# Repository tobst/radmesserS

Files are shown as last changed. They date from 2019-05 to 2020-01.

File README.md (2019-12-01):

# ESP32 BLE Distance Measurements

Distance Measurement HC-SR04 sensors connected to ESP32 pretending to be heart rate sensor for logging with fitness apps.

## Description

Inspired by the Berlin project Radmesser, this version connects to tracking apps by pretending to be a heart rate sensor. This enables you to write the distance to a gpx file and use it later in video editing software like [Dashware](http://www.dashware.net/) or [Garmin Virb Edit](https://buy.garmin.com/de-DE/DE/p/573412) to show the distance in your video.

More information can be found in the project wiki, [see here](https://github.com/tobst/radmesserS/wiki).

## Getting Started

### Hardware

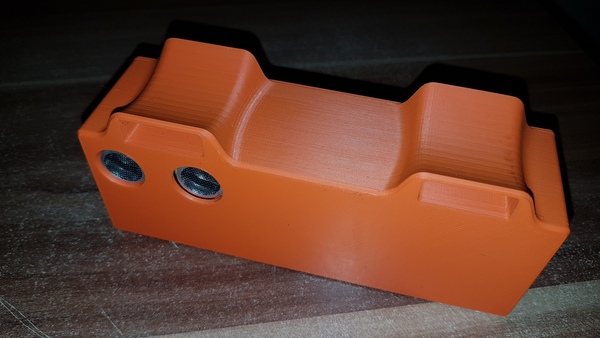
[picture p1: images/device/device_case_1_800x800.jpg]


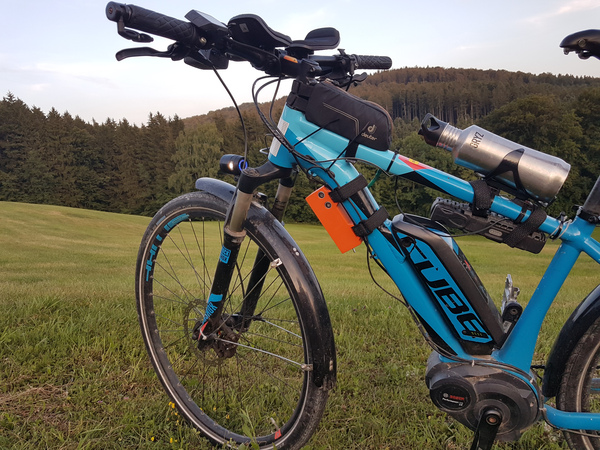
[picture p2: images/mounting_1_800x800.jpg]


The prototype by [Zweirat](https://zweirat-stuttgart.de/projekte/radmesser/) used the following:
* [ESP32](https://www.az-delivery.de/products/esp32-developmentboard)
* [LiFePo-Battery](https://www.akkuteile.de/lifepo-akkus/18650/a123-apr18650m-a1-1100mah-3-2v-3-3v-lifepo4-akku/a-1006861/)
* [Battery-Protection-Board](https://www.ebay.de/itm/202033076322)
* [LiFePo charging module](https://www.ebay.de/itm/MicroUSB-TP5000-3-6v-1A-Charger-Module-3-2v-LiFePO4-Lithium-Battery-Charging-/122164745507)
* [HC-SR04P](https://www.ebay.de/itm/183610614563)

With LiFePo Batteries you can power the device directly and avoid step-up/step-down losses that you have when using a powerbank. On the other hand you need the HC-SR04P instead of the HC-SR04 sensor if you don't have 5V power supply.

### Dependencies

* ESP32 device driver
* Neil Kolbans ESP32 BLE Library
* Arduino IDE
* [TM1637 Library](https://github.com/avishorp/TM1637) - installed through Arduino library manager
* [SSD1306 Library](https://github.com/adafruit/Adafruit_SSD1306) - installed through Arduino library manager
* [TinyGPSPlus Library](https://github.com/mikalhart/TinyGPSPlus)

### Installing

* clone or download repository
* open in Arduino IDE
* compile and upload to ESP32
* Connect sensor

### Executing program
* power up device
* Use [BLE Scanner](https://play.google.com/store/apps/details?id=com.macdom.ble.blescanner) or your favorite BLE app to send ond permanently save offset (for example the distance from sensor to handlebar)
* Start your favourite tracking app
Good results were made with [RunnerUp](https://play.google.com/store/apps/details?id=org.runnerup&hl=de), Strava had some issues on Android, look here for [alternatives](https://play.google.com/store/apps/details?id=org.runnerup&hl=de), no experience with iOS so far. 
* Connect heart rate sensor

### ToDo
* Write nice tutorial how to process video data and create synchronized overlays
* Develop an own app to record videos in loop mode and only save short clips when distance is low. At the end of the ride, ask user to confirm that a car was overtaking. Possibility to create overlays for video and report anonymous metadata of overtaking incidents (good and bad ones) to open data platform.

## Acknowledgments

Inspiration, code snippets, etc.
* [Neil Kolbans ESP32 BLE Library](https://github.com/nkolban/ESP32_BLE_Arduino)
* [Wiring up the Sensor](https://www.smarthomeng.de/entfernungsmessung-auf-basis-eines-esp32-und-smarthomeng)

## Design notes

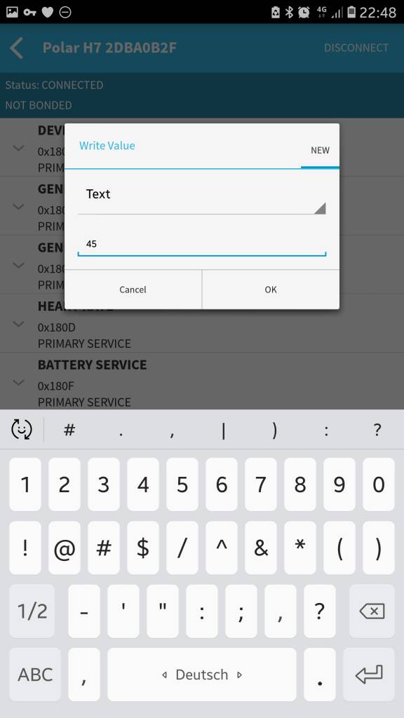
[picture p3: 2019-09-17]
images/screenshots/blescanner/ble_scanner_5.jpg

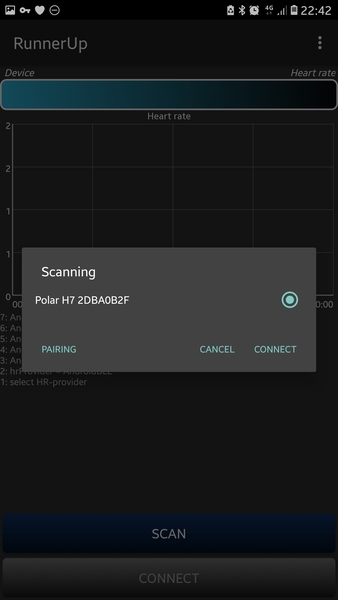
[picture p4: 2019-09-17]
images/screenshots/runnerup/runnerup_7_800x800.jpg

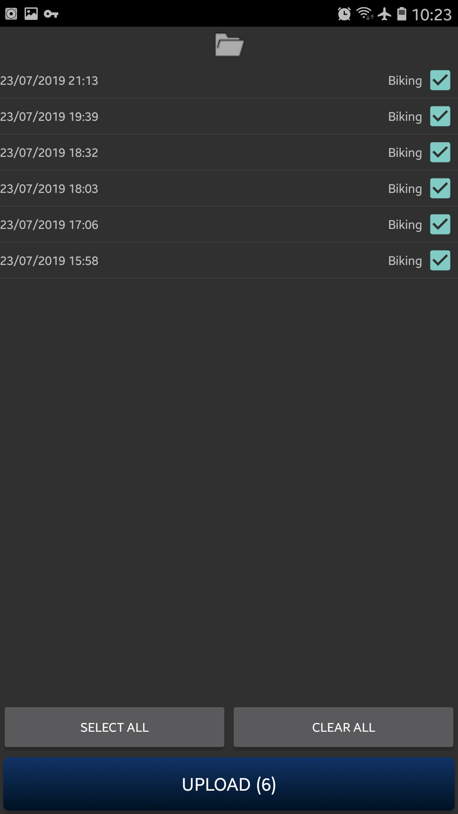
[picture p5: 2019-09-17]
images/screenshots/runnerup/export/runnerup_export_to_directory_4.jpg

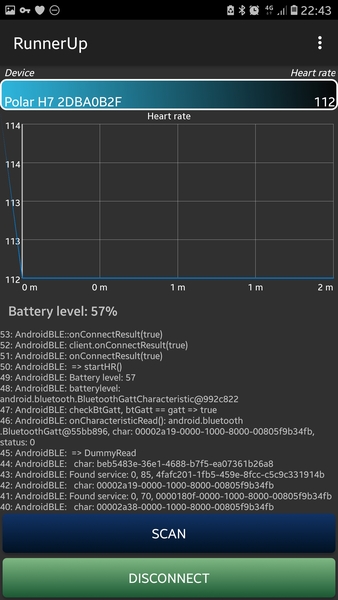
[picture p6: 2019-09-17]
images/screenshots/runnerup/runnerup_8_800x800.jpg

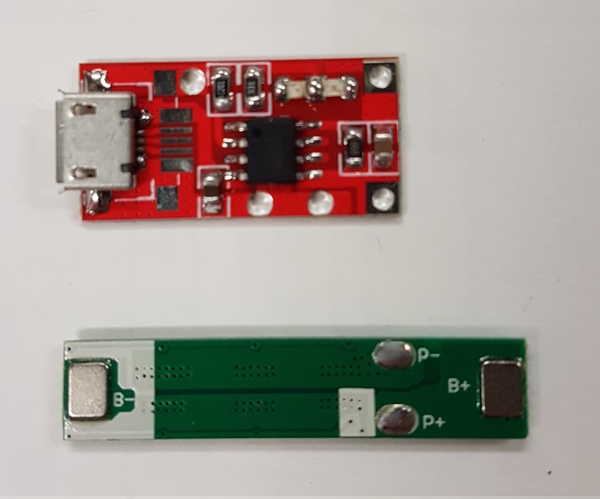
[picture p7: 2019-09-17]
images/device/TP5000-Charger-and-LiFePo-Protection-Board_800x800.jpg

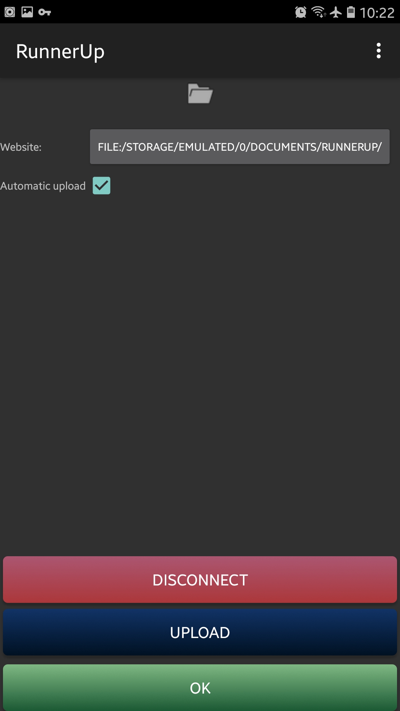
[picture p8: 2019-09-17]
images/screenshots/runnerup/export/runnerup_export_to_directory_3.jpg

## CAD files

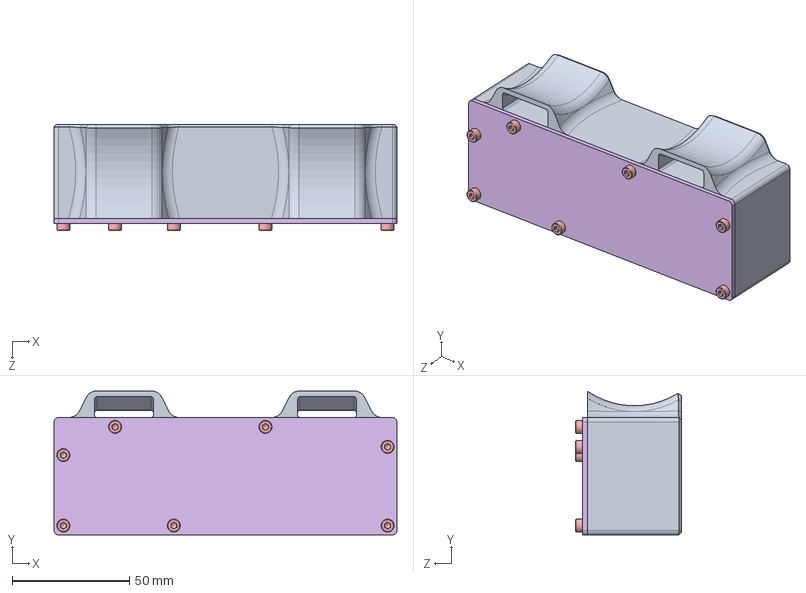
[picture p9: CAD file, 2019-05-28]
Case/TO-999.SLDASM
146.0 x 61.3 x 45.0 mm
TO-001
Battery
To-002
socket head cap screw 4762_din x 8
TP5000_placeholder
TO-004
socket head cap screw_am x 2

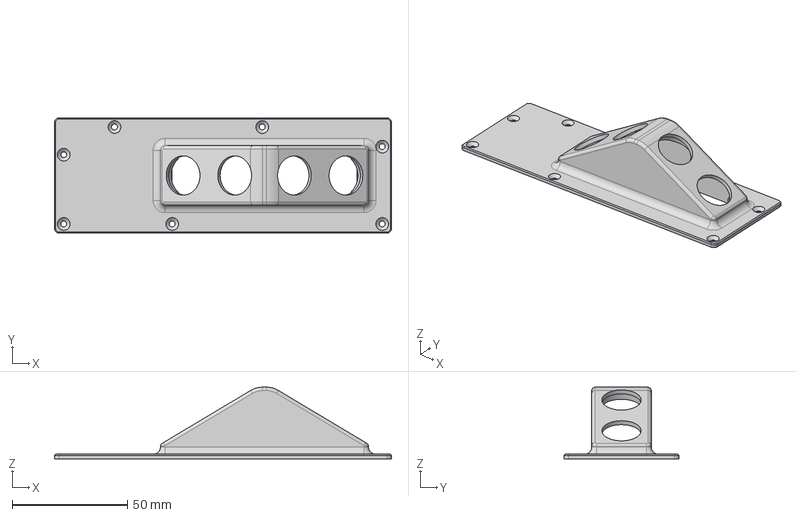
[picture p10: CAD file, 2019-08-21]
Case/TO-003_v6.step
146.0 x 50.0 x 31.1 mm

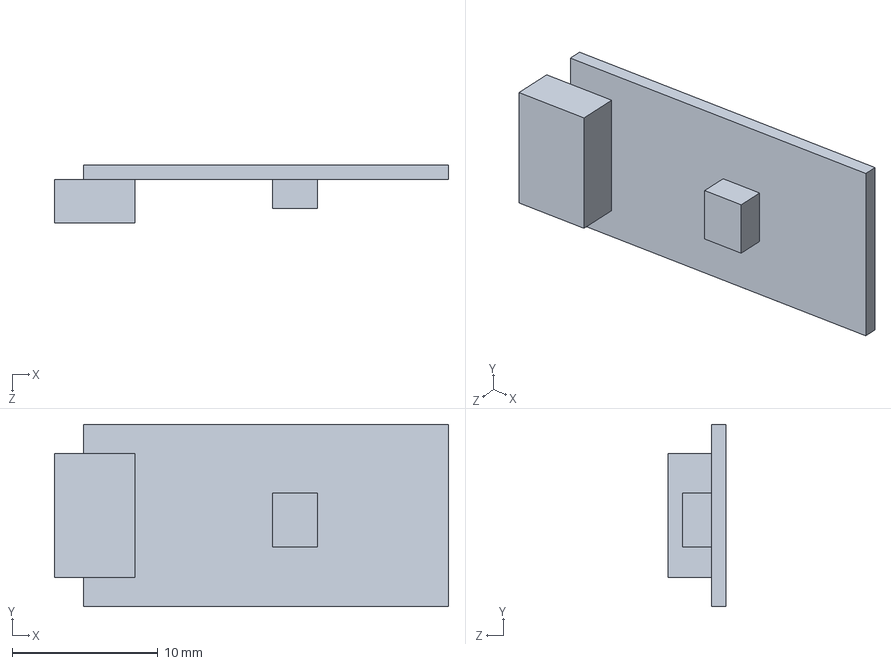
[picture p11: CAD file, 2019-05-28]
Case/TP5000_placeholder.SLDPRT
27.0 x 12.5 x 4.00 mm

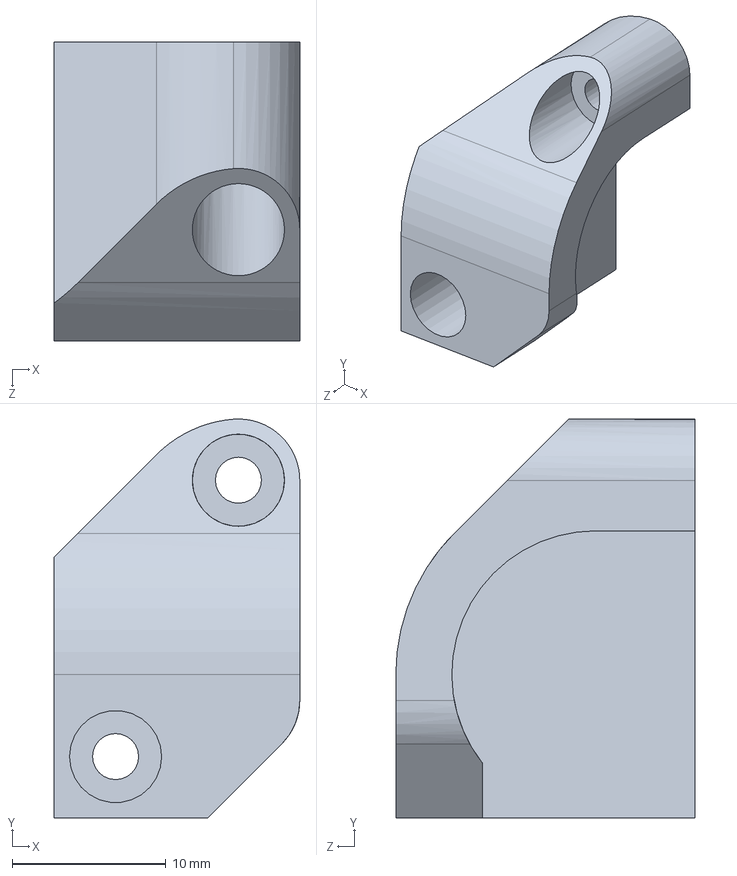
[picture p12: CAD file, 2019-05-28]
Case/To-002.SLDPRT
16.0 x 26.0 x 19.5 mm

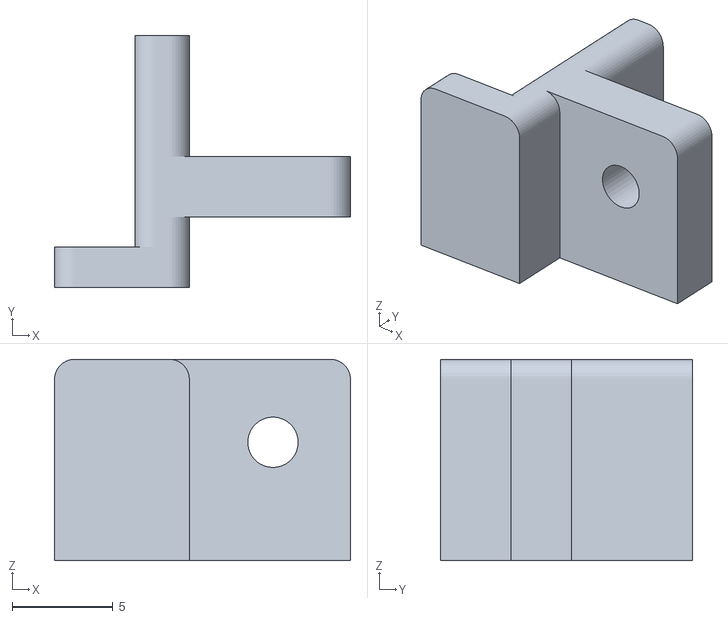
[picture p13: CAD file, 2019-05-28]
Case/TO-004_v5.STL
14.7 x 12.5 x 10.0

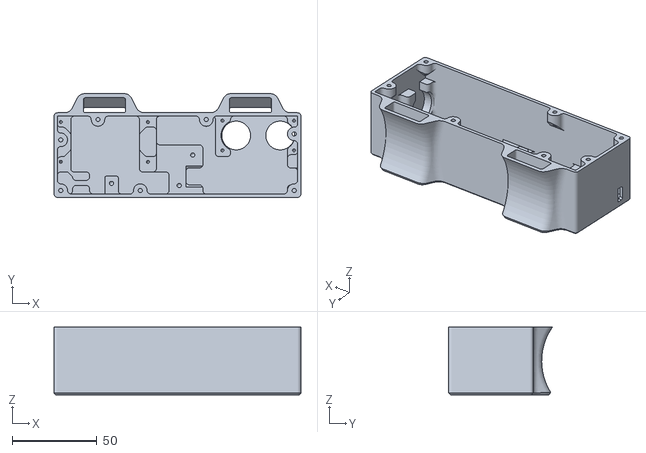
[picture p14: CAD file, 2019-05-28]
Case/TO-001_v5.STL
146.0 x 61.3 x 40.0

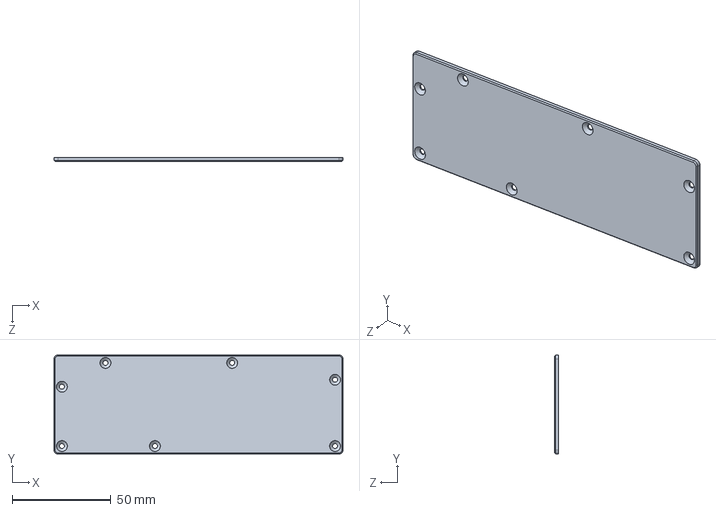
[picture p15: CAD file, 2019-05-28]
Case/TO-003.SLDPRT
146.0 x 50.0 x 2.00 mm

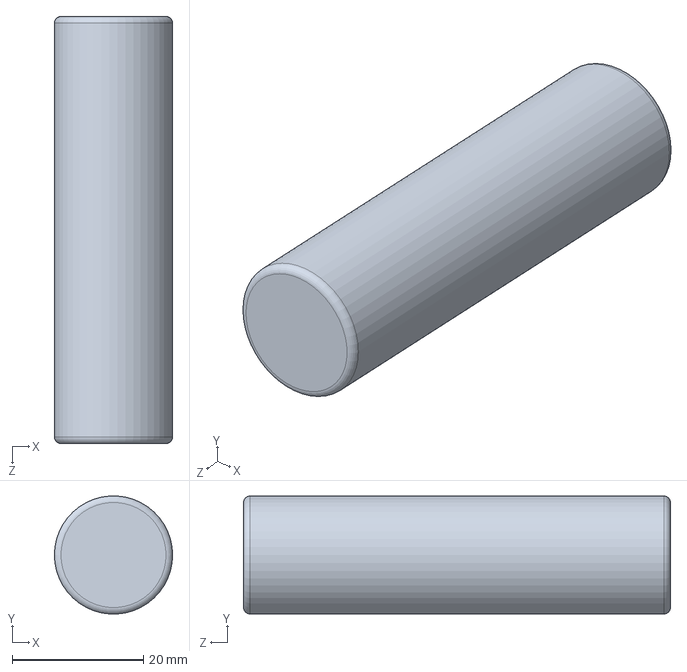
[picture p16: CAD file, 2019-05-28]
Case/Battery.SLDPRT
18.0 x 18.0 x 65.0 mm

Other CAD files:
Case/TO-001.SLDPRT
Case/TO-004.SLDPRT
Case/TO-002_v5.STL
Case/TO-003_v5.STL
Case/TO-003_v6.stl

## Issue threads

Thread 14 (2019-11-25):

use ANT+ Radar (RDR) instead of heart-rate

mfa, 2019-11-25:
https://www.thisisant.com/news/ant-wireless-releases-first-interoperable-device-profile-for-bike-radar-sen

tobst, 2019-11-27:
Good Idea. Since not all devices (e.g. IPhone) support ANT+, this should be an additional choice.

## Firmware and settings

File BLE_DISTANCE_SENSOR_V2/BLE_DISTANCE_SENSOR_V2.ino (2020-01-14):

/*
    BLE Device pretending to be a Heart Rate Measurement Device but sending distance instead

    Based on Neil Kolban example for IDF: https://github.com/nkolban/esp32-snippets/blob/master/cpp_utils/tests/BLETests/SampleNotify.cpp
    Ported to Arduino ESP32 by Evandro Copercini
    Distance Measurement by Marc Rene Friess: https://www.smarthomeng.de/entfernungsmessung-auf-basis-eines-esp32-und-smarthomeng

    Used BLE Scanner https://play.google.com/store/apps/details?id=com.macdom.ble.blescanner&hl=de to find out what original Heart Rate Sensor is doing and copied services and characteristics UUIDs

*/
#include <BLEDevice.h>
#include <BLEServer.h>
#include <BLEDescriptor.h>
#include <BLEUtils.h>
#include <BLE2902.h>
#include <Wire.h>
#include <EEPROM.h>
#define CIRCULAR_BUFFER_INT_SAFE
#include <CircularBuffer.h>
#include "displays.h"
#include "FS.h"
#include "SD.h"
#include "SPI.h"

//#include <GPX.h>

//GPX myGPX;

#include "gps.h"
#include "ble.h"
#include "vector.h"
#include "writer.h"
#include "sensor.h"

//GPS

// define the number of bytes to store
#define EEPROM_SIZE 1
#define EEPROM_SIZE 128

#define MAX_SENSOR_VALUE 255

// PINs
const int triggerPin = 15;
const int echoPin = 4;

const int PushButton = 2;


// VARs
const int runs = 20;
unsigned long measureInterval = 1000;
unsigned long timeOfLastNotificationAttempt = millis();
unsigned long timeOfMinimum = millis();
unsigned long StartTime = millis();
unsigned long CurrentTime = millis();
unsigned long buttonPushedTime = millis();

int timeout = 15000;
bool usingSD = false;
String text = "";
uint8_t minDistanceToConfirm = MAX_SENSOR_VALUE;
uint8_t confirmedMinDistance = MAX_SENSOR_VALUE;
bool transmitConfirmedData = false;
int lastButtonState = 0;
int buttonState = 0;
bool handleBarWidthReset = false;

String filename;

CircularBuffer<DataSet*, 10> dataBuffer;
Vector<String> sensorNames;

#define TASK_SERIAL_RATE 1000 // ms

uint32_t nextSerialTaskTs = 0;
uint32_t nextOledTaskTs = 0;

uint8_t handleBarWidth = 0;
bool deviceConnected = false;

class MyServerCallbacks: public BLEServerCallbacks {
    void onConnect(BLEServer* pServer) {
      deviceConnected = true;
    };

    void onDisconnect(BLEServer* pServer) {
      deviceConnected = false;
    }

};

class MyWriterCallbacks: public BLECharacteristicCallbacks {
    void onWrite(BLECharacteristic *pCharacteristic) {
      std::string value = pCharacteristic->getValue();
      handleBarWidth = atoi(value.c_str());
      timeout = 15000 + (int)(handleBarWidth * 29.1 * 2);
      EEPROM.write(0, handleBarWidth);
      EEPROM.commit();
    }
};

DisplayDevice* displayTest;
//DisplayDevice* displayTest2;

FileWriter* writer;

DistanceSensor* sensor1;
// See the following for generating UUIDs:
// https://www.uuidgenerator.net/


void setup() {
  String sensorName1 = "DistanceLeft";
  sensorNames.push_back(sensorName1);
  displayTest = new TM1637DisplayDevice;
  //displayTest2 = new SSD1306DisplayDevice;

  sensor1 = new HCSR04DistanceSensor;

  //GPS
  SerialGPS.begin(9600, SERIAL_8N1, 16, 17);
  while (!EEPROM.begin(EEPROM_SIZE)) {
    true;
  }

  readLastFixFromEEPROM();

  Serial.begin(115200);
  while (!SD.begin())
  {
    Serial.println("Card Mount Failed");
    delay(1000);
  }

  {
    Serial.println("Card Mount Succeeded");
    writer = new CSVFileWriter;
    writer->setFileName();
    writer->writeHeader();
  }
  Serial.println("File initialised");

  // initialize EEPROM with predefined size
  EEPROM.begin(EEPROM_SIZE);

  sensor1->setOffset(EEPROM.read(0));

  // PIN-Modes
  pinMode(PushButton, INPUT);

  while (gps.satellites.value() < 4)
  {
  readGPSData();
  delay(1000);
  Serial.println("Waiting for GPS fix... \n");
  }
  Serial.println("Got GPS Fix  \n");
  heartRateBLEInit();
  Serial.println("Waiting a client connection to notify...");
}

/*
   easily read and write EEPROM
*/
template <class T> int EEPROM_writeAnything(int ee, const T& value)
{
  const byte* p = (const byte*)(const void*)&value;
  int i;
  for (i = 0; i < sizeof(value); i++)
    EEPROM.write(ee++, *p++);
  return i;
}

template <class T> int EEPROM_readAnything(int ee, T& value)
{
  byte* p = (byte*)(void*)&value;
  int i;
  for (i = 0; i < sizeof(value); i++)
    *p++ = EEPROM.read(ee++);
  return i;
}

void loop() {

  DataSet* currentSet = new DataSet;
  writeLastFixToEEPROM();
  // Todo: proceed only if gps is valid and updated
  readGPSData();
  currentSet->location = gps.location;
  currentSet->altitude = gps.altitude;
  currentSet->date = gps.date;
  currentSet->time = gps.time;

  CurrentTime = millis();
  uint8_t minDistance = MAX_SENSOR_VALUE;
  int measurements = 0;
  if ((CurrentTime - timeOfMinimum ) > 5000)
  {
    minDistanceToConfirm = MAX_SENSOR_VALUE;
  }

  while ((CurrentTime - StartTime) < measureInterval)
  {
    CurrentTime = millis();
    sensor1->getMinDistance(minDistance);

    if (minDistance < minDistanceToConfirm)
    {
      minDistanceToConfirm = minDistance;
      timeOfMinimum = millis();
    }
    //displayTest->showValue(minDistanceToConfirm);
    displayTest->showValue(gps.satellites.value());
    //displayTest2->showValue(minDistanceToConfirm);

    if ((minDistanceToConfirm < MAX_SENSOR_VALUE) && !transmitConfirmedData)
    {
      buttonState = digitalRead(PushButton);
      if (buttonState != lastButtonState)
      {
        if (buttonState == LOW)
        {
          if (!handleBarWidthReset) transmitConfirmedData = true;
          else handleBarWidthReset = false;
        }
        else
        {
          buttonPushedTime = CurrentTime;
        }
      }
      else
      {
        if (buttonState == HIGH)
        {
          //Button state is high for longer than 5 seconds -> reset handlebar width
          //Todo: do it for all connected sensors 
          if ((CurrentTime - buttonPushedTime > 5000))
          {
            setHandleBarWidth(minDistanceToConfirm);
            displayTest->showValue(minDistanceToConfirm);
            //displayTest2->showValue(minDistanceToConfirm);
            delay(5000);
            handleBarWidthReset = true;
            transmitConfirmedData = false;
          }
        }
      }
      lastButtonState = buttonState;
    }
    measurements++;
  }
  currentSet->sensorValues.push_back(minDistance);

  //if nothing was detected, write the dataset to file, otherwise write it to the buffer for confirmation
  if ((minDistance == MAX_SENSOR_VALUE) && dataBuffer.isEmpty())
  {
    if (writer) writer->writeData(currentSet);
    delete currentSet;
  }
  else
  {
    dataBuffer.unshift(currentSet);
  }

  Serial.write("min. distance: ");
  Serial.print(minDistance) ;
  Serial.write(" cm,");
  Serial.print(measurements);
  Serial.write(" measurements  \n");

  uint8_t buffer[2];
  uint8_t isit8or16bit = 0;
  buffer[0] = isit8or16bit;
  if (transmitConfirmedData)
  {
    buffer[1] = minDistanceToConfirm;
    // make sure the minimum distance is saved only once
    using index_t = decltype(dataBuffer)::index_t;
    index_t j;
    for (index_t i = 0; i < dataBuffer.size(); i++)
    {
      if (dataBuffer[i]->sensorValues[0] == minDistanceToConfirm)
      {
        j = i;
      }
    }
    for (index_t i = 0; i < dataBuffer.size(); i++)
    {
      if (i != j)
      {
        dataBuffer[i]->sensorValues[0] = MAX_SENSOR_VALUE;
      }
    }

    while (!dataBuffer.isEmpty())
    {
      DataSet* dataset = dataBuffer.shift();
      Serial.printf("Trying to write set to file\n");
      if (writer) writer->writeData(dataset);
      Serial.printf("Wrote set to file\n");
      delete dataset;
    }
    minDistanceToConfirm = MAX_SENSOR_VALUE;
    transmitConfirmedData = false;
  }
  else
  {
    buffer[1] = MAX_SENSOR_VALUE;
  }

  if (dataBuffer.isFull())
  {
    DataSet* dataset = dataBuffer.shift();
    dataset->sensorValues[0] = MAX_SENSOR_VALUE;
    Serial.printf("Buffer full, writing set to file\n");
    if (writer) writer->writeData(dataset);
    Serial.printf("Deleting dataset\n");
    delete dataset;
  }

  if (deviceConnected) {
    Serial.printf("*** NOTIFY: %d ***\n", buffer[1] );
    heartRateBLENotify(buffer);
  }

  unsigned long ElapsedTime = CurrentTime - StartTime;
  StartTime = CurrentTime;
  Serial.write(" Time elapsed: ");
  Serial.print(ElapsedTime);
  Serial.write(" milliseconds\n");
}

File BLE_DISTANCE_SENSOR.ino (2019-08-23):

/*
    BLE Device pretending to be a Heart Rate Measurement Device but sending distance instead
    
    Based on Neil Kolban example for IDF: https://github.com/nkolban/esp32-snippets/blob/master/cpp_utils/tests/BLETests/SampleNotify.cpp
    Ported to Arduino ESP32 by Evandro Copercini
    Distance Measurement by Marc Rene Friess: https://www.smarthomeng.de/entfernungsmessung-auf-basis-eines-esp32-und-smarthomeng
    
    Used BLE Scanner https://play.google.com/store/apps/details?id=com.macdom.ble.blescanner&hl=de to find out what original Heart Rate Sensor is doing and copied services and characteristics UUIDs
    
*/
#include <BLEDevice.h>
#include <BLEServer.h>
#include <BLEDescriptor.h>
#include <BLEUtils.h>
#include <BLE2902.h>
#include <Wire.h>
#include <EEPROM.h>

// define the number of bytes to store
#define EEPROM_SIZE 1

// PINs
const int triggerPin = 15;
const int echoPin = 4;

// VARs
const int runs = 20;
unsigned long measureInterval = 1000;
unsigned long StartTime = millis();
unsigned long CurrentTime = millis();
uint8_t handleBarWidth = 0;
int timeout = 15000;

BLECharacteristic *pCharacteristic;
BLECharacteristic *pSystemIDCharcateristic;
BLECharacteristic *pModelNumberStringCharacteristic;
BLECharacteristic *pSerialNumberStringCharacteristic;
BLECharacteristic *pFirmwareRevisionCharacteristic;
BLECharacteristic *pHardwareRevisionCharacteristic;
BLECharacteristic *pSoftwareRevisionCharacteristic;
BLECharacteristic *pManufacturerNameCharacteristic;
BLECharacteristic *pSensorLocationCharacteristic;
BLECharacteristic *pHeartRateControlPointCharacteristic;
BLECharacteristic *pBatteryCharacteristics;
BLECharacteristic *pHandleBarWidthCharacteristic;

bool deviceConnected = false;

// See the following for generating UUIDs:
// https://www.uuidgenerator.net/


#define DEVICE_INFORMATION_UUID "0000180A-0000-1000-8000-00805F9B34FB"
#define SYSTEM_ID_UUID "00002a23-0000-1000-8000-00805f9b34fb"
#define SYSTEM_ID_VALUE_HEX 0x0BBA2DFEFF1A9EA0
#define MODEL_NUMBER_STRING_UUID "00002a24-0000-1000-8000-00805f9b34fb"
#define MODEL_NUMBER_STRING_VALUE "H7"
#define SERIAL_NUMBER_STRING_UUID "00002a25-0000-1000-8000-00805f9b34fb"
#define SERIAL_NUMBER_STRING_VALUE 20182DBA0B
#define SERIAL_NUMBER_STRING_VALUE_HEX 0x3230313832444241304200
#define FIRMWARE_REVISON_UUID "00002a26-0000-1000-8000-00805f9b34fb"
#define FIRMWARE_REVISON_VALUE "1.4.0"
#define HARDWARE_REVISION_UUID "00002a27-0000-1000-8000-00805f9b34fb"
#define HARDWARE_REVISION_VALUE_HEX 0x33393034343032342E313000
#define SOFTWARE_REVISION_UUID "00002a28-0000-1000-8000-00805f9b34fb"
#define SOFTWARE_REVISION_VALUE_HEX 0x483720332E312E3000
#define MANUFACTURER_NAME_STRING_UUID "00002a29-0000-1000-8000-00805f9b34fb"
#define MANUFACTURER_NAME_STRING_VALUE_HEX 0x506F6C617220456C656374726F204F7900

#define HEART_RATE_SERVICE_UUID        "0000180D-0000-1000-8000-00805F9B34FB"
#define HEART_RATE_CHARACTERISTIC_UUID "00002a37-0000-1000-8000-00805f9b34fb"
#define CLIENT_CHARCTERISTIC_CONFIG_DESCRIPTOR_UUID "00002902-0000-1000-8000-00805f9b34fb"

#define BODY_SENDOR_LOCATION_UUID "00002a38-0000-1000-8000-00805f9b34fb"
#define BODY_SENDOR_LOCATION_VALUE "1"

#define BATTERY_SERVICE_UUID "0000180f-0000-1000-8000-00805f9b34fb"
#define BATTERY_CHARACTERISTIC_UUID "00002A19-0000-1000-8000-00805F9B34FB"

#define HEART_RATE_CONTROL_POINT_UUID "00002a39-0000-1000-8000-00805f9b34fb"
#define HEART_RATE_CONTROL_POINT_VALUE "1"

#define GENERIC_ACCESS_UUID        "00001800-0000-1000-8000-00805F9B34FB"
#define GENERIC_ACCESS_DEVICE_NAME_CHARACTERISTIC_UUID "00002a00-0000-1000-8000-00805f9b34fb"

#define HANDLEBAR_WIDTH_SERVICE_UUID "4fafc201-1fb5-459e-8fcc-c5c9c331914b"
#define HANDLEBAR_WIDTH_CHARACTERISTIC_UUID "beb5483e-36e1-4688-b7f5-ea07361b26a8"


class MyServerCallbacks: public BLEServerCallbacks {
    void onConnect(BLEServer* pServer) {
      deviceConnected = true;
    };

    void onDisconnect(BLEServer* pServer) {
      deviceConnected = false;
    }

};

class MyWriterCallbacks: public BLECharacteristicCallbacks {

    void onWrite(BLECharacteristic *pCharacteristic) {
      std::string value = pCharacteristic->getValue();
      handleBarWidth = atoi(value.c_str());
      timeout = 15000 + (int)(handleBarWidth * 29.1 * 2);
      EEPROM.write(0, handleBarWidth);
      EEPROM.commit();
    }
};



void setup() {
  Serial.begin(115200);
  
  // initialize EEPROM with predefined size
  EEPROM.begin(EEPROM_SIZE);

  handleBarWidth = EEPROM.read(0);
  timeout = 15000 + (int)(handleBarWidth * 29.1 * 2);

  // PIN-Modes
  pinMode(triggerPin, OUTPUT);
  pinMode(echoPin, INPUT);
  digitalWrite(triggerPin, HIGH);

  
  // Create the BLE Device
  BLEDevice::init("Polar H7 2DBA0B2F");

  // Create the BLE Server
  BLEServer *pServer = BLEDevice::createServer();
  pServer->setCallbacks(new MyServerCallbacks());

  // Create the BLE Services
  BLEService *pDeviceInfoService = pServer->createService(DEVICE_INFORMATION_UUID);
  BLEService *pHeartRateService = pServer->createService(HEART_RATE_SERVICE_UUID);
  BLEService *pBatteryLevelService = pServer->createService(BATTERY_SERVICE_UUID);
  BLEService *pHandleBarWidthService = pServer->createService(HANDLEBAR_WIDTH_SERVICE_UUID);

  
  // Create a BLE Characteristic
  pCharacteristic = pHeartRateService->createCharacteristic(
                      HEART_RATE_CHARACTERISTIC_UUID,
                      BLECharacteristic::PROPERTY_READ   |
                      //BLECharacteristic::PROPERTY_WRITE  |
                      BLECharacteristic::PROPERTY_NOTIFY //|
                      //BLECharacteristic::PROPERTY_INDICATE
                    );
 pHeartRateControlPointCharacteristic = pHeartRateService->createCharacteristic( HEART_RATE_CONTROL_POINT_UUID,
                      BLECharacteristic::PROPERTY_READ   |
                      BLECharacteristic::PROPERTY_WRITE
                      //BLECharacteristic::PROPERTY_NOTIFY //|
                      //BLECharacteristic::PROPERTY_INDICATE
                    );

 pHandleBarWidthCharacteristic = pHandleBarWidthService->createCharacteristic(HANDLEBAR_WIDTH_CHARACTERISTIC_UUID,
                      BLECharacteristic::PROPERTY_READ   |
                      BLECharacteristic::PROPERTY_WRITE
                      //BLECharacteristic::PROPERTY_NOTIFY //|
                      //BLECharacteristic::PROPERTY_INDICATE
                    );

 pSensorLocationCharacteristic = pHeartRateService->createCharacteristic(BODY_SENDOR_LOCATION_UUID, BLECharacteristic::PROPERTY_READ);
 uint8_t locationValue = 1;
 pSensorLocationCharacteristic->setValue(&locationValue,1);
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

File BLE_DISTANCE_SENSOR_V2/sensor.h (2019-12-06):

class Sensor
{
  public:
    Sensor() {}
    virtual ~Sensor() {}
    virtual void init() = 0;

  protected:

  private:
};

class DistanceSensor : public Sensor
{
  public:
    DistanceSensor() : Sensor() {
    }
    ~DistanceSensor() {}
    virtual void init()
    {

    }
    void getMinDistance(uint8_t& min_distance);
    virtual float getDistance() = 0;
    void setOffset(uint8_t offset) {
      m_offset = offset;
    }
  protected:
    uint8_t m_offset = 0;
  private:
    unsigned long m_measureInterval = 1000;

};

class HCSR04DistanceSensor : public DistanceSensor
{
  public:
    HCSR04DistanceSensor() : DistanceSensor() {
      pinMode(m_triggerPin, OUTPUT);
      pinMode(m_echoPin, INPUT);
      digitalWrite(m_triggerPin, HIGH);
    }
    ~HCSR04DistanceSensor() {}
    void init() {
    }
    float getDistance();
    void setOffset(uint8_t offset) {
      m_offset = offset;
      m_timeout = 15000 + (int)(m_offset * 29.1 * 2);
    }
  protected:
  private:
    int m_triggerPin = 15;
    int m_echoPin = 4;
    int m_timeout = 15000;
};

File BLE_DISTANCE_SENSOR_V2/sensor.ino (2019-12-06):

void DistanceSensor::getMinDistance(uint8_t& min_distance) {
  float dist;
  dist = getDistance() - float(m_offset);
  if ((dist > 0.0) && (dist < float(min_distance)))
  {
    min_distance = uint8_t(dist);
  }
  else
  {
    dist = 0.0;
  }
  if (usingSD)
  {
    //text += String(dist);
    //text += ";";
  }
  delay(20);
}

float HCSR04DistanceSensor::getDistance() {
  float duration = 0;
  float distance = 0;

  digitalWrite(m_triggerPin, LOW);
  delayMicroseconds(2);
  noInterrupts();
  digitalWrite(m_triggerPin, HIGH);
  delayMicroseconds(10);
  digitalWrite(m_triggerPin, LOW);
  duration = pulseIn(m_echoPin, HIGH, m_timeout); // Erfassung - Dauer in Mikrosekunden
  interrupts();

  distance = (duration / 2) / 29.1; // Distanz in CM
  return (distance);
}

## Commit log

2019-05-27 write handlebar width to device
2019-05-28 added stl and sldprt files for case
    [Battery.SLDPRT, TO-001.SLDPRT, TO-001_v5.STL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]
2019-05-29 explanation about different sensors
2019-06-07 sample data created with RunnerUp, uploaded to Strava and downloaded as gpx
2019-07-31 added sample overlays created vith virb edit
2019-08-05 added example pictures for mounting on bike
2019-08-07 open sensor case
2019-08-21 alternative lid to host two extra sensors
    [TO-003_v6.step, TO-003_v6.stl]
2019-09-17 Update readme
    add image of device, link to the wiki
2019-09-17 add another image of mounted device
2019-09-23 added ridiculously amateurish sketch with protection board
2019-09-30 version to display distance on MAX7219 driven LED matrices
2019-11-28 new version with push button, various displays, gps, sd card support, early development state
2019-12-12 button state change detection
2020-01-14 wait for gps fix
    [BLE_DISTANCE_SENSOR_V2.ino]
